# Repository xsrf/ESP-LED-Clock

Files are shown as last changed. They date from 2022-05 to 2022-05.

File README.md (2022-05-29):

# ESP8266 based 7 segment RGB LED Clock
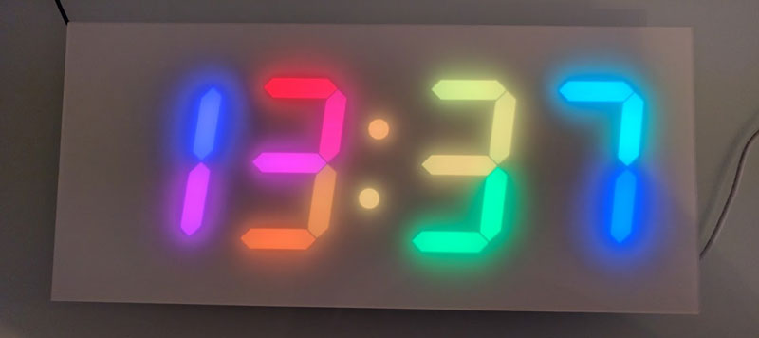
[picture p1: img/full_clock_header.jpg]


This project is a selfmade 450x200mm huge full color 7 segment RGB LED Clock, involving custom PCBs and 3D printing.

It's build using an ESP8266 (ESP-12/07 module or WeMos D1 Mini) and digitally controlled RGB LEDs like ES2812B/SK6812. The LEDs are placed on custom PCBs (one for each digit) that are sitting in a 3D printed housing. All digits are then stuck to the back of an acrylic sheet.

It also features a temperature and humidity sensor as well as a light sensor to automatically adjust the brightness.

It's running on 5V (MicroUSB or Barrel-Jack) and consumes about 1W (depending on brightness and color of course).

*Disclaimer: This is not really a full assembly guide. Don't expect much.*

# PCB and electronics BOM
- 59x 5050 RGB LED WS2812B/SK6812 (https://www.aliexpress.com/item/32814778563.html)
- With ESP8266 ESP12/07 Module:
  - ESP12/07 module
  - AMS1117-3.3
  - 3x 10k 0805
  - 2x 10uF 0805
  - 1x 220k 0805
  - 1x 100k 0805
- With WeMos D1 Mini:
  - WeMos D1 Mini V3 (https://www.aliexpress.com/item/32651747570.html)
- Temp/Humidity Sensor (choose one, optional)
  - BME280 I2C (https://www.aliexpress.com/item/1005003622447376.html)
  - DHT22 (https://www.aliexpress.com/item/1041496689.html)
- GL5528 LDR (https://www.aliexpress.com/item/1005003629058275.html)
- 22k 0805 (for LDR)
- 74AHCT1G125GW TTL Buffer (https://www.aliexpress.com/item/32871606717.html)
- 1uF 0805 (for TTL Buffer)
- DC-002 3.5 x 1.35mm Barrel Jack Socket (https://www.aliexpress.com/item/4000647661560.html)
- 5V/2A Power supply (https://www.amazon.de/dp/B00DS6UXLO/)

# Other Parts
- 3D Printed parts
- 450x200mm 2-4mm thick acrylic plexiglas
- white adhesive film (d-c-fix Design-Bastelklebefolie 45cm x 2m weiß seidenmatt 346-0001) (https://www.amazon.de/dp/B08M6518C7/)
- Silicone/Glue/Acryl cartridge (https://www.amazon.de/dp/B003YO87M2/)

# 3D Printing
## Material
The material needs to meet three basic criteria:
- **rigid** - otherwise the modules will flex and create gaps between the module and the plexiglas front
- **white** - to create an even lighting inside a segment
- **opaque** - so lit segments won't bleed light through to the neighboring segments

PLA is the best material choice for rigidity.

While white would be the obvious best color choice, I found that most white PLA is not opaque enough and light bleeds through to neighboring segments.
One solution is to use dark/black filament and paint it white afterwards (at least the inside facing walls of the segments).

Alternatively I had good results with special opaque white filament, like **kexcelled PETGk5 Basic Light Shielding White** (e.g. available here: https://ruhr3d.shop/products/petg-spezial-lichtdicht-1-75mm-natur-1-0kg ). However, since it is PETG, it tends to warp and flex more than PLA :/

I'm yet to find a perfect material to recommend 🤷‍♂️

## Other considerations
The print settings are not really important. Choose a thick layer height, like 0.3mm or more. It's really not important for the looks or functionality, but speeds up printing.

Dial in the extrusion with such that the external perimeters do not have gap fill, this otherwise slows down printing a lot. e.g. ~0.52mm work fine.

The most important feature of the print is the first perimeter of each segment. Make sure the perimeter lays down flat and closes perfectly, especially on the thin wall between segments.

When printed, try to cut/sand off any blobs that may prevent the PCB from sitting flush with the segments.

# Component pictures

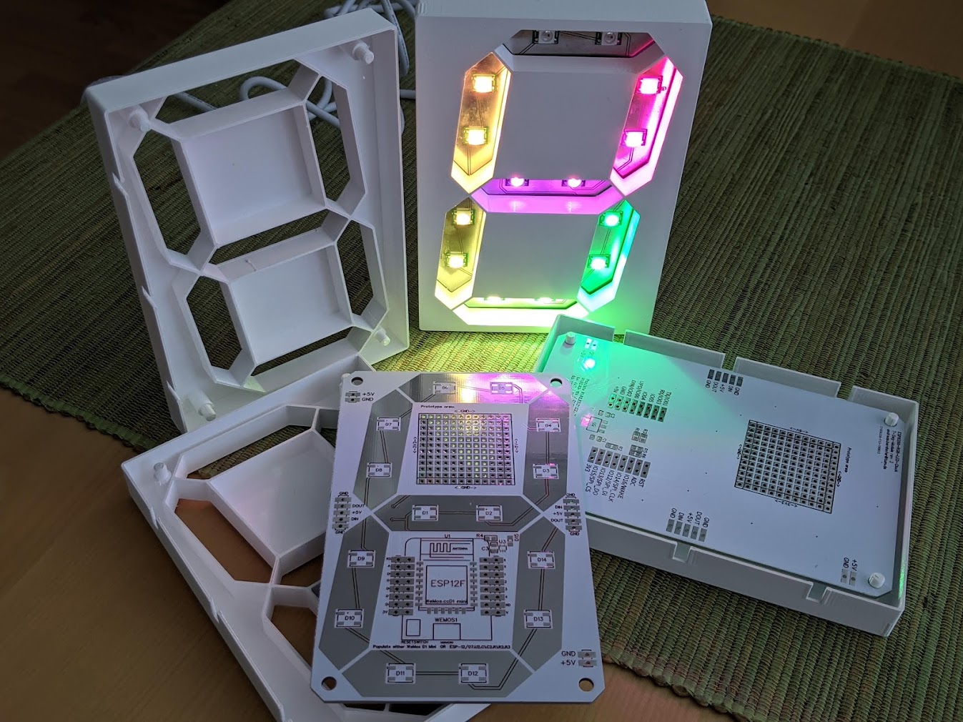
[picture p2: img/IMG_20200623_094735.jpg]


The main component is the 7 segment display module, consisting of a custom PCB with LEDs populated (the ESP is only needed on the first one) and fit into it's 3D printed housing. These are then put together to form the Clock.

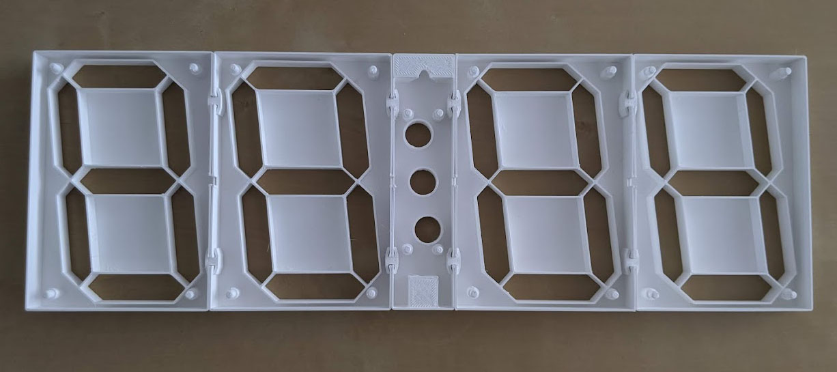
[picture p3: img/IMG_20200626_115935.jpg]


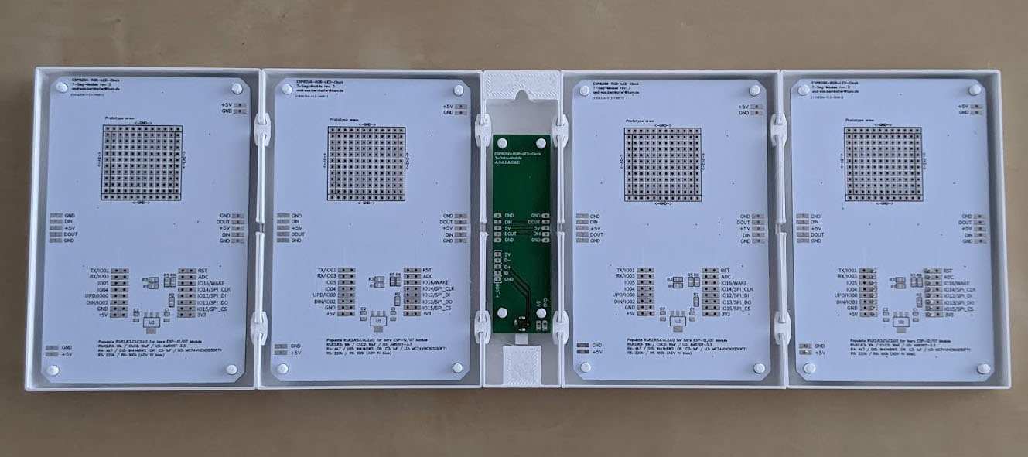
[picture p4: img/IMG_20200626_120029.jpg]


All the 3D prints are held together with simple clips and are later glued to the acrylic.

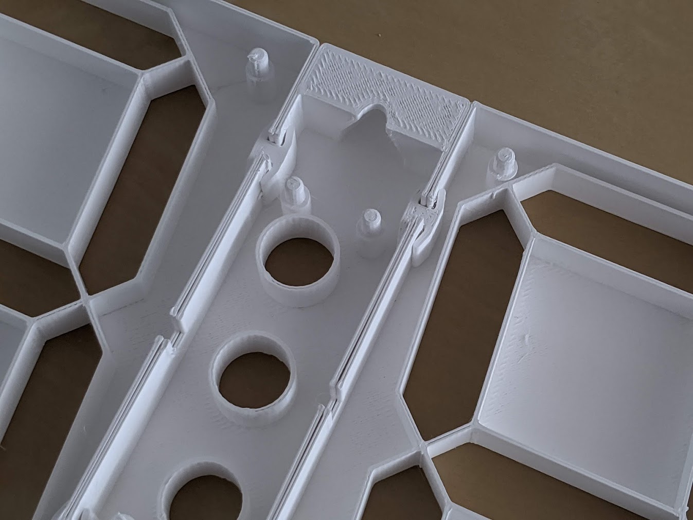
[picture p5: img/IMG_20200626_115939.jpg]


Wiring is pretty simple - there is only power and one data line looping through all segments

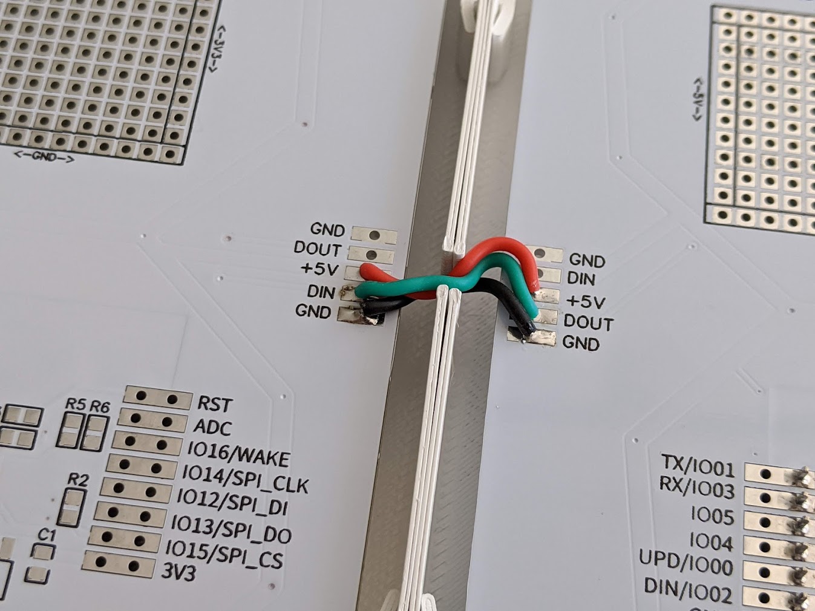
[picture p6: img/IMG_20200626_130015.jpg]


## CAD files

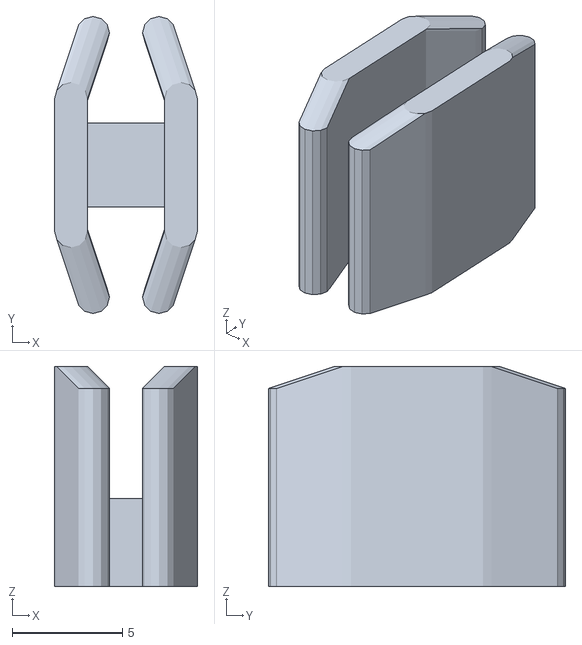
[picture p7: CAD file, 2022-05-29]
3d-models/builds/20210313_conn_clip.stl
6.50 x 13.5 x 10.0

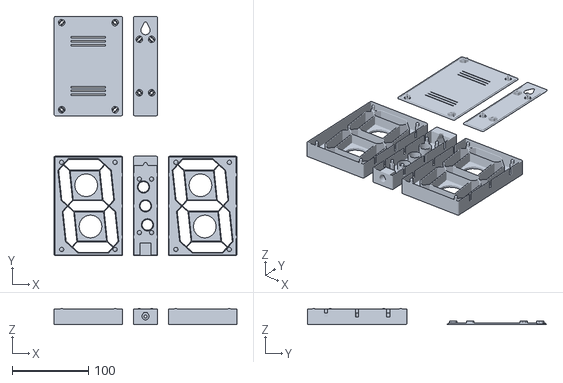
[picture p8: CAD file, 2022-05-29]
3d-models/builds/20210313_7seg_plate.stl
239.6 x 313.0 x 21.0

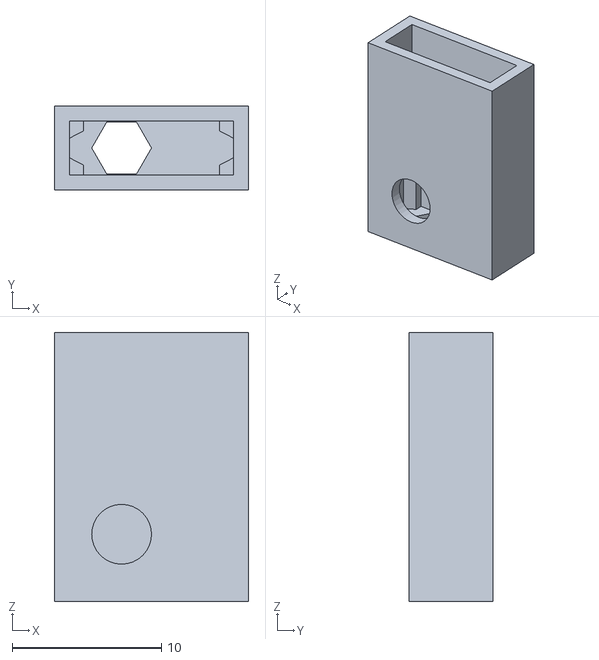
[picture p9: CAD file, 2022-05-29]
3d-models/builds/20210313_bme280_case.stl
13.0 x 5.60 x 18.0

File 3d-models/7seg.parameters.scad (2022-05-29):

// Basic case dimensions
$ox = 90; // Width of digit case
$oy = 130; // Height of digit case
$oz = 20; // Thickness of digit case
$ot = 1; // Wall thickness on the sides
$of = 3; // Wall/floor thickness on the front face (1mm for PLA, 3mm for PET)
$or = 1.5; // Corner radius of outer shell

$odx = 32; // Width of colon display case

// Digit dimensions
$skew = -6;
$dx = 68;
$dy = 122;
$dt = 14;
$dh = 15;

// PCB Dimensions
$pcb_t = 1.6;
$pcb_holes_x = 70;
$pcb_holes_y = 114;
$pcb_holes_d = 3.75; // Adjust this for standoff fit
// Colon display PCB
$pcb_holes_dots_x = 16;
$pcb_holes_dots_y = 70;

// Lid dimensions
$lid_lip_inset = 0.4;
$lt = 1; // lid brim thickness
$lf = 1; // lid back thickness

$lightguard_separation = 0;

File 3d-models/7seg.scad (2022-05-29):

/*
    All parts needed for a giant RGB LED Clock

    Sorry, this code is all over the place and not well commented...
    You shouldn't use it anyways, create your own modules using 7seg.lib.scad ;)
*/
use <7seg.lib.scad> // https://github.com/xsrf/7-seg-scad
include <7seg.parameters.scad>


// Main four 7 seg frames
translate([-$dx*1.1,0,0]) segFrame(1);
translate([+$dx*1.1,0,0]) segFrame(2);

// Colon / dot Frame
dotFrame();

// Lids
translate([-$dx*1.1,$dy*1.5,0]) segLid();
translate([0,$dy*1.5,0]) dotLid();

/*
    FRAMES
*/
module segFrame($side_cutouts = 2) {
    difference() {
        // outer body (with .5mm phase)
        frame($ox,$oy,$oz);
        // digits cutout
        translate([0,0,$oz/2-11]) digit_hull($dx,$dy,$dt,1+$lightguard_separation*2,$oz-4,$skew);
        // joiner cutouts
        if($side_cutouts >= 2) mirror([1,0,0]) translate([$ox/2,0,$oz]) joiner_cutouts();
        if($side_cutouts >= 1) mirror([0,0,0]) translate([$ox/2,0,$oz]) joiner_cutouts();
        // center holes to glue down segments
        translate([tan($skew)*($dy/4-$dt/4),$dy/4-$dt/4,-0.1]) cylinder(r=($dx-$dt*2)/2-5,h=4,$fn=16);
        translate([-tan($skew)*($dy/4-$dt/4),-($dy/4-$dt/4),-0.1]) cylinder(r=($dx-$dt*2)/2-5,h=4,$fn=16);
    }
    digit_outline($dx,$dy,$dt,1,$dh,$skew);
    pcb_standoffs_seg();
    %pcb_dummy();
}

module dotFrame() {
    M = [ [ 1  , 0  , 0    ],
       [ tan($skew)  , 1  , 0  ],  // The "0.7" is the skew value; pushed along the y axis
       [ 0  , 0  , 1    ] ] ;
    difference() {
        // outer body (with .5mm phase)
        frame($odx,$oy,$oz);
        // dot cutouts
        for(i=[-1,0,1]) translate([0,i*24.8,-$oz/2]*M) cylinder(r=7,h=$oz,$fn=32);
        mirror([1,0,0]) translate([$odx/2,0,$oz]) joiner_cutouts();
        mirror([0,0,0]) translate([$odx/2,0,$oz]) joiner_cutouts();
        hull() {
            translate([0,-$oy/2-1,$dh - 4.5]) rotate([-90,0,0]) cylinder(r=9/2, h=10, $fn=32);
            translate([0,-$oy/2-1,$dh - 3]) rotate([-90,0,0]) cylinder(r=9/2, h=10, $fn=6);
        }
    }
    // dot shells
    difference() {
        for(i=[-1,0,1]) translate([0,i*24.8,0]*M) cylinder(r=7+$ot,h=$dh,$fn=32);
        for(i=[-1,0,1]) translate([0,i*24.8,-0.1]*M) cylinder(r=7,h=$dh+1,$fn=32);
    }
    // hook
    translate([0,$oy/2-12/2,0]) difference() {
        translate([0,-$ot/2,$oz/2]) cube([$odx-$ot*2,12-$ot,$oz],center=true);
        hull() {
            translate([0,-12/2,0]) cylinder(r=3,h=$oz+1,$fn=16);
            translate([0,-12/2+2,0]) cylinder(r=2,h=$oz+1,$fn=16);
        }
        hull() {
            translate([0,-12/2,0]) cylinder(r=3,h=$oz-2,$fn=16);
            translate([0,-12/2+2,0]) cylinder(r=2,h=$oz-2,$fn=16);
            translate([0,-12/2,0]) cylinder(r=2,h=$oz-2,$fn=16);
            translate([0,-12/2,0]) cylinder(r=7,h=$oz-10,$fn=16);
            translate([0,12/2,0]) cylinder(r=2,h=$oz-10,$fn=16);
        }
    }
    // power cutout
    difference() {
        $ins = 16.5;
        translate([0,-$oy/2 + $ins/2,($dh-$of+2)/2+$of]) cube([15,$ins,($dh-$of+2)],center=true); // power cutout
        translate([0,-$oy/2,$dh - 4.5]) rotate([-90,0,0]) cylinder(r=4.5/2, h=$ins, $fn=6);
        hull() {
            translate([0,-$oy/2-1,$dh - 4.5]) rotate([-90,0,0]) cylinder(r=9/2, h=$ins, $fn=32);
            translate([0,-$oy/2-1,$dh - 3]) rotate([-90,0,0]) cylinder(r=9/2, h=$ins, $fn=6);
        }
    }
    pcb_standoffs_dots();    
    %pcb_dummy_dot();
}

/*
    LIDS
*/
module segLid() {
    $ra = $or;
    $iri = 2; // lip inner radius
    difference(){
        difference() {
            union() {
                hull() for(i=[-1,1]) for(j=[-1,1]) translate([($ox/2-$ra-0.25)*i,($oy/2-$ra)*j,0]) cylinder(r=$ra,h=$lt,$fn=32); // reduce x by 0.5 so lids fit next together
                hull() for(i=[-1,1]) for(j=[-1,1]) translate([($ox/2-$iri-1-$lid_lip_inset-$ot)*i,($oy/2-$iri-1-$lid_lip_inset-$ot)*j,0]) cylinder(r=$iri+1,h=$lt+1,$fn=32);
            }
            hull() for(i=[-1,1]) for(j=[-1,1]) translate([($ox/2-$iri-$lid_lip_inset-1-$ot)*i,($oy/2-$iri-$lid_lip_inset-1-$ot)*j,$lf]) cylinder(r=$iri,h=$lt+1,$fn=32);
        }
        for(i=[-1,1]) for(j=[-1,0,1]) translate([0,$oy/4*i + j*5,0]) cube([$ox/2,2,20],center=true);
        for(i=[1,-1]) for(j=[1,-1]) translate([i*$pcb_holes_x/2,j*$pcb_holes_y/2,0]) 
            rotate([0,0,45*j*i]) lid_standoff_cutout();
    }
    for(i=[1,-1]) for(j=[1,-1]) translate([i*$pcb_holes_x/2,j*$pcb_holes_y/2,0]) 
        rotate([0,0,45*j*i]) difference() {
            lid_standoff_support();
            lid_standoff_cutout();
        }
}


module dotLid() {
    $ra = $or;
    $iri = 2; // lip inner radius
    difference(){
        difference() {
            union() {
                hull() for(i=[-1,1]) for(j=[-1,1]) translate([($odx/2-$ra-0.25)*i,($oy/2-$ra)*j,0]) cylinder(r=$ra,h=$lt,$fn=32); // reduce x by 0.5 so lids fit next together
                hull() for(i=[-1,1]) for(j=[-1,1]) translate([($odx/2-$iri-1-$lid_lip_inset-$ot)*i,($oy/2-$iri-1-$lid_lip_inset-$ot)*j,0]) cylinder(r=$iri+1,h=$lt+1,$fn=32);
            }
            hull() for(i=[-1,1]) for(j=[-1,1]) translate([($odx/2-$iri-$lid_lip_inset-1-$ot)*i,($oy/2-$iri-$lid_lip_inset-1-$ot)*j,$lf]) cylinder(r=$iri,h=$lt+1,$fn=32);
            translate([0,$oy/2 - 12.5/2,$lt/2 + $lt]) cube([$odx,12.5,$lt],center=true); // remove lip on top where 12mm hook support is
        }
        for(i=[1,-1]) for(j=[1,-1]) translate([i*$pcb_holes_dots_x/2,j*$pcb_holes_dots_y/2,0]) 
            rotate([0,0,45*j*i]) lid_standoff_cutout();
        // hook entry
        hull() {
            translate([0,$oy/2-9,-1]) cylinder(r=2,h=20,$fn=16);
            translate([0,$oy/2-18,-1]) cylinder(r=6,h=20,$fn=16);
        }
    }
    for(i=[1,-1]) for(j=[1,-1]) translate([i*$pcb_holes_dots_x/2,j*$pcb_holes_dots_y/2,0]) 
        rotate([0,0,45*j*i]) difference() {
            lid_standoff_support();
            lid_standoff_cutout();
        }
}


/*
    Support Modules
*/

module joiner_cutouts() {
    for(i=[-1,0,1]) translate([-$ot/2,i*($dy/3),0]) joiner_cutout();
}

module joiner_cutout() {
    cube([$ot+4,4.2,$oz],center=true);
    difference() {
        cube([$ot+4,16,$oz],center=true);
        cube([$ot,16,$oz],center=true);
    }
}

module lid_standoff_cutout() translate([0,0,-0.1]) {
    $rr = $pcb_holes_d/2;
    $ch = $oz;
    cylinder(r=$rr,h=$ch,$fn=16);
    difference() {
        cylinder(r=$rr+2.5,h=$ch,$fn=16);
        cylinder(r=$rr+1,h=$ch,$fn=16);
        cube([3.5,20,2*$ch],center=true);
    }
    cube([1.5,8.5,2*$ch],center=true);
}

module lid_standoff_support() {
    $rr = $pcb_holes_d/2;
    $support_height = $oz - $dh - $pcb_t + $lt;
    cylinder(r=$rr+1,h=$support_height,$fn=16);
    translate([0,0,$support_height/2]) cube([3.5,10.5,$support_height],center=true);
}

module frame($dx,$dy,$h) {
    $ra = $or;
    $ri = $ra - $ot;
    difference() {
        hull() {
            for(i=[-1,1]) for(j=[-1,1]) translate([($dx/2-$ra)*i,($dy/2-$ra)*j,0.5]) cylinder(r=$ra,h=$h-0.5,$fn=32);
            for(i=[-1,1]) for(j=[-1,1]) translate([($dx/2-$ra)*i,($dy/2-$ra)*j,0]) cylinder(r1=$ra-0.5,r2=$ra,h=0.5,$fn=32);
        }
        hull() {
            for(i=[-1,1]) for(j=[-1,1]) translate([($dx/2-$ra)*i,($dy/2-$ra)*j,$of]) cylinder(r=$ri,h=$h,$fn=32);
        }
    }
}

// Dummy for my PCB
module pcb_dummy() {
    translate([0,0,$dh]) linear_extrude(height=$pcb_t) difference() {
        polygon(points=[[36,62],[40,58],[40,-58],[36,-62],[-36,-62],[-40,-58],[-40,58],[-36,62]]);
        for(i=[1,-1]) for(j=[1,-1]) translate([i*$pcb_holes_x/2,j*$pcb_holes_y/2,0]) circle(r=2, $fn=24);
    }
}

module pcb_dummy_dot() {
    translate([0,0,$dh]) linear_extrude(height=$pcb_t) difference() {
        polygon(points=[[-12,39],[12,39],[12,-43],[-12,-43]]);
        for(i=[1,-1]) for(j=[1,-1]) translate([i*$pcb_holes_dots_x/2,j*$pcb_holes_dots_y/2,0]) circle(r=2, $fn=24);
    }
    translate([-5/2,-43-5,$dh-8]) cube([5,12,8]); // barrel jack
    translate([-8/2,-43-2,$dh-3]) cube([8,6,3]); // micro usb
}

module pcb_standoff() {
    cylinder(r=$pcb_holes_d/2+1,h=$dh,$fn=16);
    cylinder(r=$pcb_holes_d/2,h=($oz+$lf)-0.5,$fn=16);
    translate([0,0,($oz+$lf)-0.5]) cylinder(r1=$pcb_holes_d/2,r2=$pcb_holes_d/2-0.5,h=0.5,$fn=16);
}

module pcb_standoffs_seg() {
    for(i=[1,-1]) for(j=[1,-1]) translate([i*$pcb_holes_x/2,j*$pcb_holes_y/2,0]) pcb_standoff();
}

module pcb_standoffs_dots() {
    for(i=[1,-1]) for(j=[1,-1]) translate([i*$pcb_holes_dots_x/2,j*$pcb_holes_dots_y/2,0]) pcb_standoff();
}

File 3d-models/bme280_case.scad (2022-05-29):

$x = 10.5;
$y = 1.6;
$z = 13.6;

%translate([0,0,$z/2]) cube([$x,$y,$z],center=true);

difference() {
    translate([0,0,9-1]) cube([$x+2.5,$y+4,18],center=true);
    //translate([0,0,10]) cube([$x+1,$y+0.4,20],center=true);
    translate([0,0,10]) cube([$x-1.4,$y+2,20],center=true);
    hull() {
        translate([0,0,10]) cube([$x+0.5,$y-0.3,20],center=true);
        translate([0,0,10]) cube([$x-2,$y+1,20],center=true);
    }


    translate([0,0,10+$z-3]) cube([$x+0.5,$y+2,20],center=true);
    translate([-2.0,0,-5]) cylinder(r=2,h=10,$fn=6);
    translate([-2.0,0,3.5]) rotate([90,0,0]) cylinder(r=2,h=10,$fn=32);
}

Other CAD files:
3d-models/conn_clip.scad
3d-models/7seg.lib.scad
